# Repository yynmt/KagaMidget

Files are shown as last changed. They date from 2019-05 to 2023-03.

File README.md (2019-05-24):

# KagaMidget

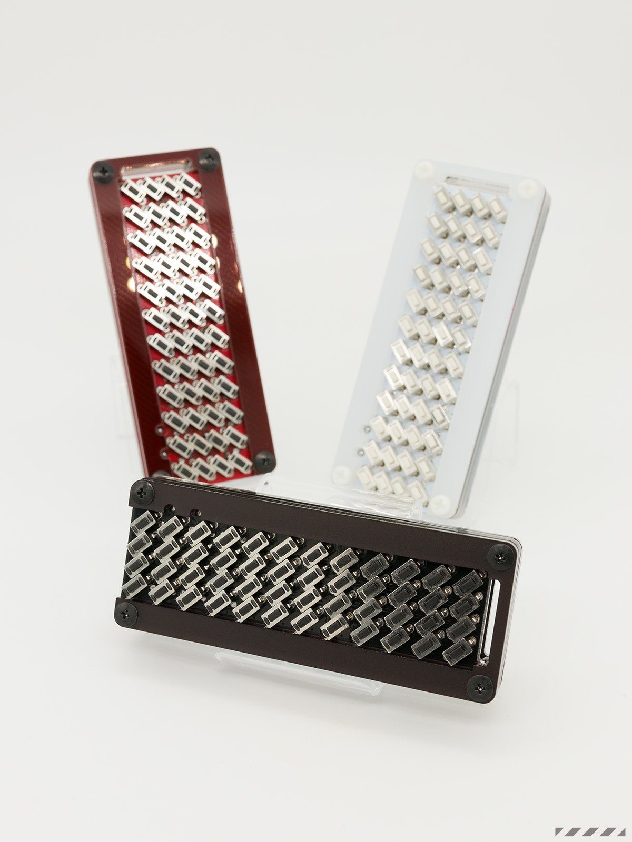
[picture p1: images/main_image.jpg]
KagaMidget


KagaMidget is tiny 40% keybord.

## Build Guide

- [ビルドガイド](/docs/buildguide_jp.md)
- [Build Guide](/docs/buildguide_en.md)

## Plates

- [all](../plates/all.svg)
- [top](../plates/top.svg)
- [middle](../plates/middle.svg)
- [bottom](../plates/bottom.svg)

## How to get

- [BOOTH](https://yynmt.booth.pm/items/1300918)

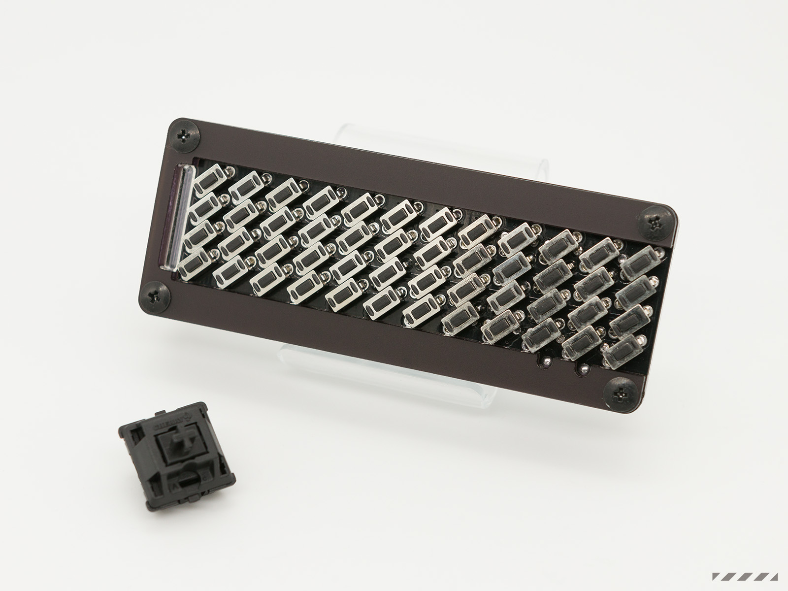
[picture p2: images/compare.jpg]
compare


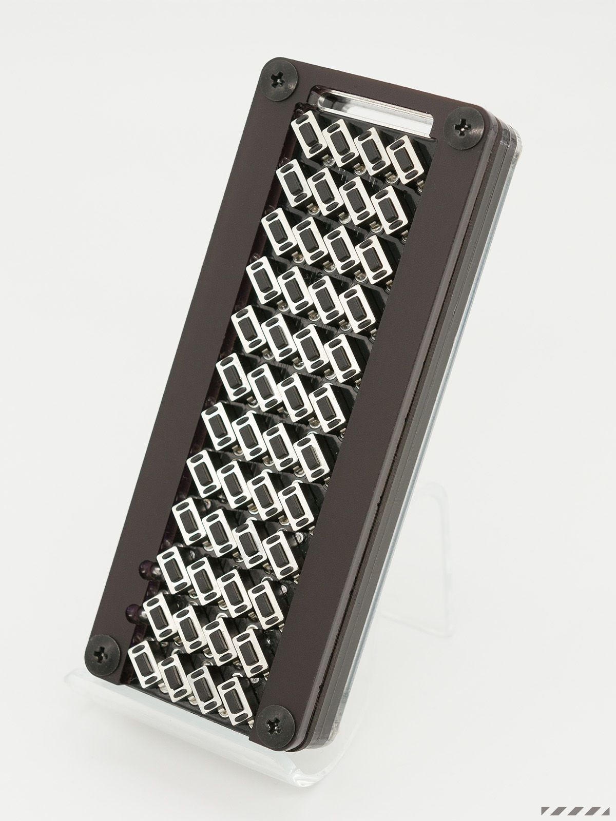
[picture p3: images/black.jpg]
black
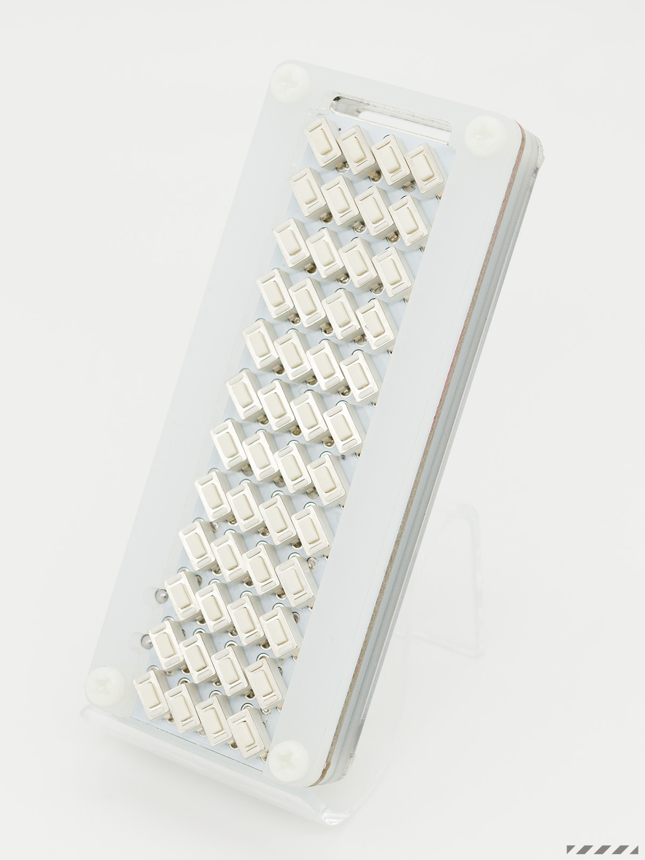
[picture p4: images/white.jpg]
white
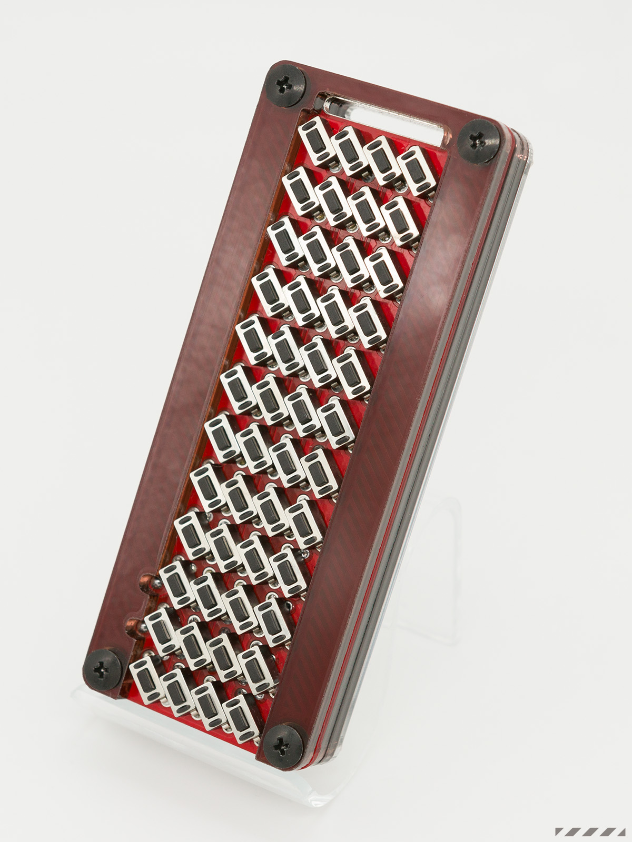
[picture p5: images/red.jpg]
red
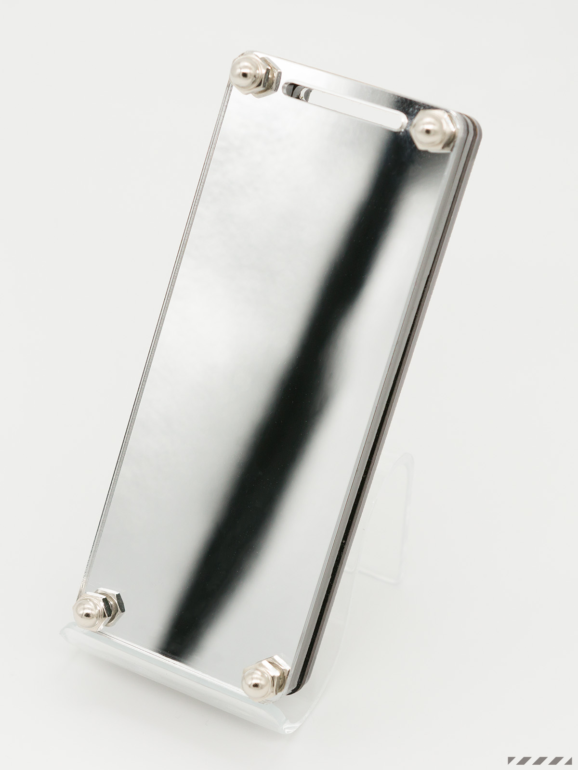
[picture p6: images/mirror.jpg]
mirror
|||||
|:---:|:---:|:---:|:---:|
|blabk|white|red|mirror |

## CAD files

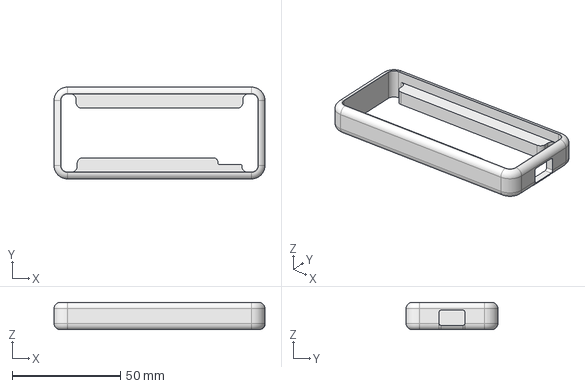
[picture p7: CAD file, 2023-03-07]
case/case_3mm.step
97.4 x 42.4 x 12.6 mm

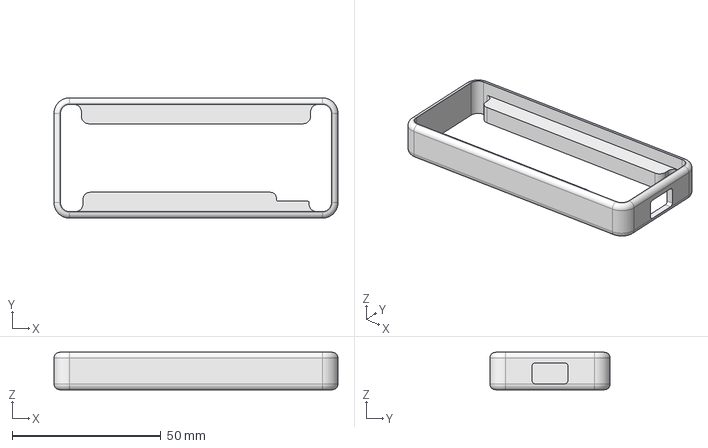
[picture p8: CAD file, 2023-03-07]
case/case_2mm.step
95.4 x 40.4 x 12.6 mm

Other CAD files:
case/case_2mm.stl
case/case_3mm.stl

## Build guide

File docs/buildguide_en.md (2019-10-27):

# KagaMidget Build Guide

## Parts

|| Name | Qty | Notes |
|:---:|---|---:|---|
|1|PCB|1||
|2|Top plate|1||
|3|Middle plate|2||
|4|Bottom plate|1||
|5|Tact switch(3x6mm)|50|Available for purchase [here](http://akizukidenshi.com/catalog/g/gP-08073/)|
|6|Diode(1N4148W)|50|Available for purchase [here](http://akizukidenshi.com/catalog/g/gI-07084/)|
|7|Pin socket(14x1)|2|Available for purchase [here](http://akizukidenshi.com/catalog/g/gC-00661/)|
|8|Screw(M3 15mm)|4||
|9|Cap nut(M3)|4||
|10|ProMicro/Proton C/Elite-C|1|ProMicro available [here](https://yushakobo.jp/shop/promicro-spring-pinheader/)|
|11|Pin header(12x1)|2|Included in ProMicro|
|12|USB cable|1| |

## Build process

1. Yell for motivation.
2. Trim the feet of the tact switch with a nipper (easier to do now than later).
3. Fold the included socket to 12 pins and trim the legs with a nipper.
4. Solder 48 diodes to the bottom of PCB - pay attention to the direction of the diodes. Lines on the diodes should match the lines on the PCB.
5. Solder two pin sockets to the bottom of the PCB.
6. Solder 49 tact switches to the top of the PCB.
7. Insert the pin header supplied with Microcontroller into the pin socket and trim the correct length.
8. Flash `kagamidget` in [QMK](https://qmk.fm) onto the Microcontroller.
9. Solder the trimmed header to the Microcontroller.
10. Test all the buttons.
11. Screw the PCB between the plates.
12. You're finished! Have fun :)

## Plates data

Distributing plate data.
The thickness of the middle plate needs 6 mm.

- [all](../plates/all.svg)
- [top](../plates/top.svg)
- [middle](../plates/middle.svg)
- [bottom](../plates/bottom.svg)

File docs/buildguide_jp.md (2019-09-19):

# KagaMidget ビルドガイド

## キットの内容物

|| 名前 | 数量 | 備考 |
|:---:|---|---:|---|
|1|PCB|1||
|2|トッププレート|1||
|3|ミドルプレート|2||
|4|ボトムミラープレート|1||
|5|タクトスイッチ(3x6mm)|50|[秋月電子通商](http://akizukidenshi.com/catalog/g/gP-08073/)より購入可能|
|6|ダイオード(1N4148W)|50|[秋月電子通商](http://akizukidenshi.com/catalog/g/gI-07084/)より購入可能|
|7|ピンソケット(14x1)|2|[秋月電子通商](http://akizukidenshi.com/catalog/g/gC-00661/)より購入可能|
|8|ネジ(M3 15mm)|4||
|9|袋ナット(M3)|4||

## キット以外に必要な部品

|| 名前 | 数量 | 備考 |
|:---:|---|---:|---|
|1|ProMicro|1|[遊舎工房](https://yushakobo.jp/shop/promicro-spring-pinheader/)より購入可能|
|2|ピンヘッダ(12x1)|2|ProMicroに付属|
|3|MicroUSBケーブル|1| |

## 組み立て方

1. 大きな声を出してやる気を奮い立たせます。
1. タクトスイッチの足をニッパーで短く切ります。
1. ピンソケットを12の長さに折って足をニッパーで短く切ります。
1. PCBにダイオード48個をハンダ付けします。
1. PCBにピンソケット2個をハンダ付けします。
1. PCBにタクトスイッチ49個をハンダ付けします。
1. ProMicro付属のピンヘッダをピンソケットに挿し込み短く切ります。
1. 短く切ったピンヘッダのピンにProMicroを通してハンダ付けします。
1. QMKファームウェアを書き込んで動作確認をします。
1. 各プレートでPCBを挟んでネジ留めします。
1. 完成です。やったね。

もっとちゃんとしたビルドガイドは[こちら](https://udaryyyy.hatenadiary.com/entry/2019/07/16/020428)

## プレートデータ配布

トッププレート、ミドルプレート、ボトムミラープレートのデータを配布しています。
お好みのカラーのアクリルをカットして自由にカスタマイズすることができます。
middleは厚みが6mm必要ですので使用するアクリルの厚みによって数量を調整します。

- [all](../plates/all.svg)
- [top](../plates/top.svg)
- [middle](../plates/middle.svg)
- [bottom](../plates/bottom.svg)

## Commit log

2019-04-29 add plates
2023-03-07 Add 3d print case models
    [case_2mm.step, case_2mm.stl, case_3mm.step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]
